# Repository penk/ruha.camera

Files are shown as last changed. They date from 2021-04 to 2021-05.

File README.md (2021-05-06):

# RUHAcam 

A 3D Printable Retro-style Raspberry Pi HQ Camera



## Bill of Materials 

- Raspberry Pi Zero WH + microSD card 
- Raspberry Pi HQ Camera 
- 16mm 10MP Telephoto Lens 
- 2.2" TFT Display 
- TP4056 Micro USB Battery Charger 
- MT3608 DC-DC Step Up Boost Module 
- 2000mAh Lipo battery 
- Power switch 
- Shutter button 
- Dupont jumper wires 
- 3D printed case (see [STL](STL) folder)
- Leather patches for couch (optional)



## Schematic

- Power from converter connects to Pi's `5V` (pin 4) and `GND` (pin 6)
- Shutter button connects to `GPIO26` (pin 37) and `GND` (pin 39) 

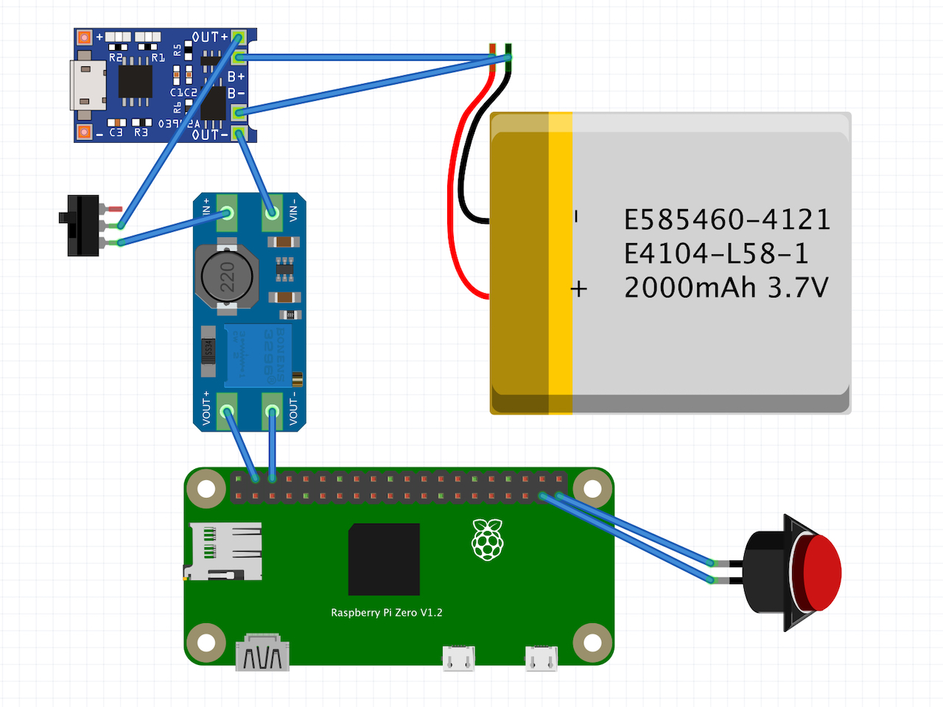
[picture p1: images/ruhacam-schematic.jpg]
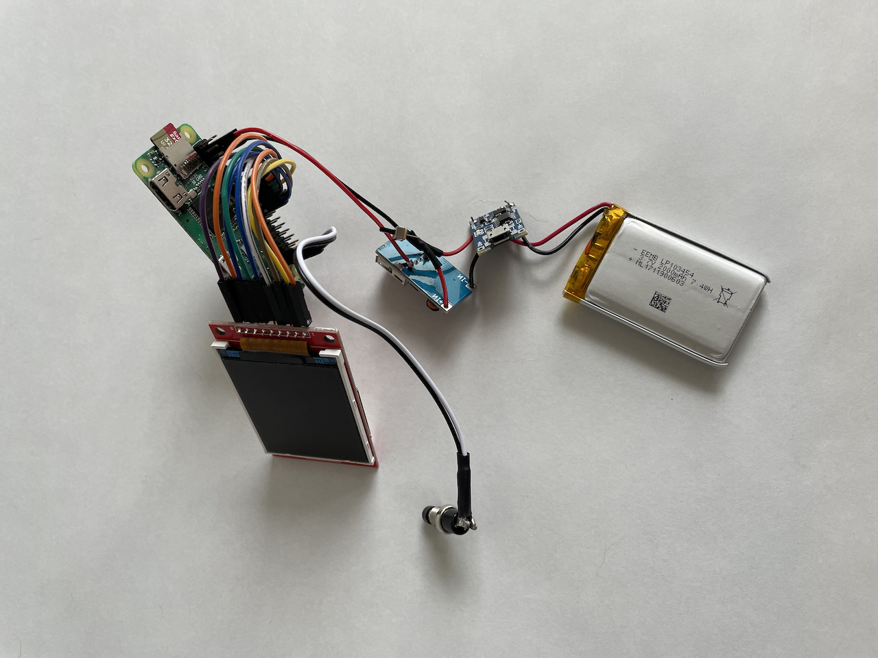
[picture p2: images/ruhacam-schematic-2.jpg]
|  |  |
|-----|-----|

| Raspberry Pi pins | TFT display |
|---|---|
| 3v3 (pin 17) | VCC |
| GND (pin 20) | GND |
| GPIO8 (pin 24) | CS |
| GPIO23 (pin 16) | RESET |
| GPIO24 (pin 18) | DC |
| GPIO10 (pin 19) | MOSI |
| GPIO11 (pin 23) | SCK | 
| GPIO18 (pin 12) | LED | 
| GPIO9 (pin 21) | MISO | 

## Assembly

|  |  |
|---|---|
|  |  |

## Software 

Flash Raspberry Pi OS to micro SD card. Then add following lines into `config.txt`: 

    gpu_mem=256
    dtoverlay=rpi-display
    display_rotate=2

For application, simply execute this script after boot: 

    from gpiozero import Button
    from picamera import PiCamera
    import time

    button = Button(26)

    with PiCamera() as camera:
        camera.resolution = (4056, 3040)
        camera.framerate = 5
        frame = int(time.time())
        camera.start_preview()
        while True:
            button.wait_for_press()
            camera.capture('/home/pi/Pictures/%03d.jpg' % frame)
            frame += 1

## Sample Pictures 

|  |  |
|---|---|
|  |  |

## Copyright and License

Copyright (c) 2021 Ruha Cheng & Penk Chen. All rights reserved. 

All files are licensed under MIT license, see the LICENSE for more information.

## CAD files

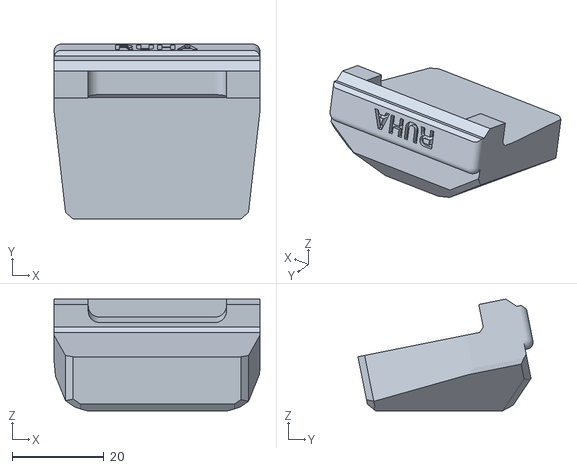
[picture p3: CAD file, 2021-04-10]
STL/ruhacam-top-deco.stl
44.8 x 38.1 x 24.3

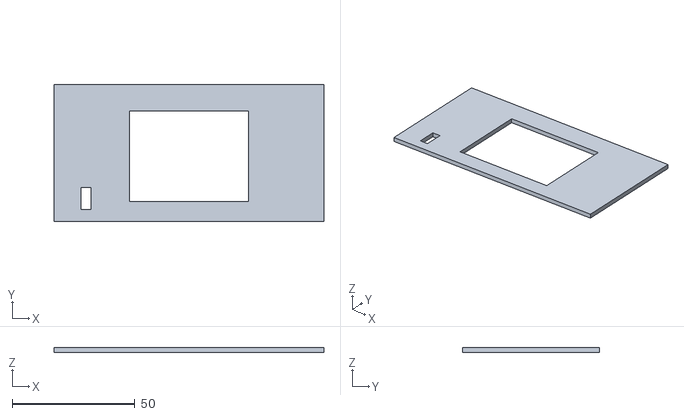
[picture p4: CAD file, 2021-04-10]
STL/ruhacam-cover.stl
109.9 x 55.6 x 2.00

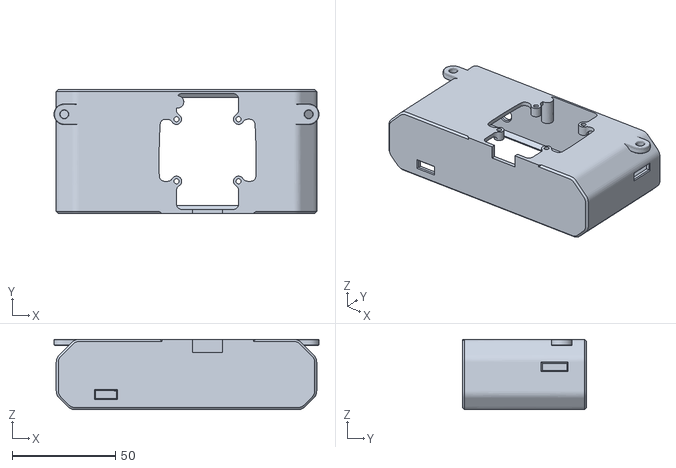
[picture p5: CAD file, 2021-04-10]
STL/ruhacam-body.stl
128.2 x 60.0 x 34.0

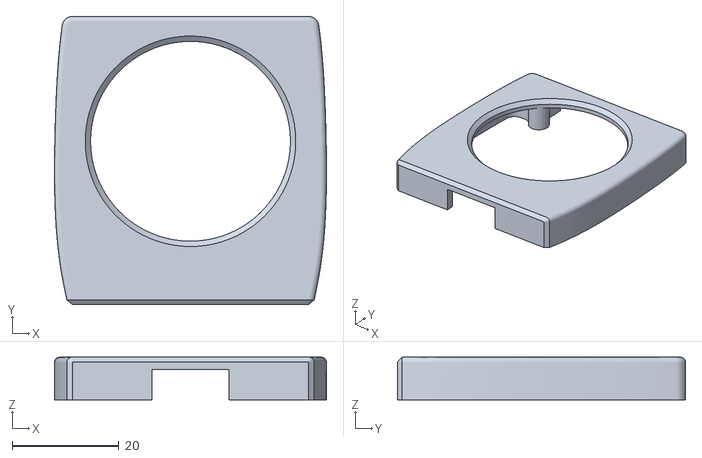
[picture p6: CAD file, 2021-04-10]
STL/ruhacam-mount.stl
50.9 x 54.0 x 8.00

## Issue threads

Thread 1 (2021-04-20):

Did you mean Pi Zero WH?

ghostis, 2021-04-20:
I think the BOM should specify the Pi Zero WH (wireless + header) or specify that you have to solder on the header if you have a Pi Zero W.

penk, 2021-04-21:
Good catch, fixed in latest commit.

Closed 2021-04-21.

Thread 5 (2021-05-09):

Power switch and shutter button

mikecheng2626, 2021-05-09:
Hi,

What kind of power switch and shutter button are they? Just trying to make sure my grocery list is the same.

penk, 2021-05-09:
Hi, I use the spare parts I had at hand, but I believe anything works -- as long as you can tweak the shape on printed parts so it fits.

Amazon link attached for reference:
https://www.amazon.co.jp/dp/B01LYVYQNO
https://www.amazon.co.jp/dp/B0822GHZ36

Closed 2021-05-09.

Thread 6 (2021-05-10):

Link to display?

btilford, 2021-05-10:
Most displays I've found are 2.8"

Also, are some of these parts like the top glued together? The mount looks like it has structure for screws that line up with the main body but, there aren't guide holes.

penk, 2021-05-10:
Hi,

Here's one of those 2.2 TFT I found on Amazon, no affiliation: http://amazon.com/dp/B01CZL6QIQ
All 3D parts are glued; HQ camera and Pi Zero can be screwed into place (or using hot glue if needed).

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

Closed 2021-05-10.

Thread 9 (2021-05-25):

TFT Display Driver

nishabe, 2021-05-25:
I have this display: http://amazon.com/dp/B01CZL6QIQ
However, I have difficulties in making it work.

Could you please share which driver you have used?
Any link to the steps much appreciated.
@penk

RadiantFeline, 2021-05-29:
I'm using the same board with this https://github.com/juj/fbcp-ili9341

penk, 2021-05-30:
Hi, I'm simply using the rpi-display dtoverlay, (`dtoverlay=rpi-display` in `config.txt`).
Source:
https://github.com/raspberrypi/linux/blob/rpi-5.10.y/arch/arm/boot/dts/overlays/rpi-display-overlay.dts

I find this post very helpful:
https://tejaswid.github.io/wikitm/rpi/pi-tft-display

Closed 2021-05-30.

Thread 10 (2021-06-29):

Touch Screen Funtionality?

Nathan116, 2021-06-29:
I was wondering if the 2.2" tft was supposed to be a touchscreen. If not, would it be possible to add touchscreen capabilities to be able to change camera settings on the go? I understand that this is a DIY camera, more of a "proof-of-concept" than anything else, but I just feel like having the ability to change some of the basic camera settings in the camera would be cool.

penk, 2021-07-01:
Hi @Nathan116, you're right, touch support is part of the plan.

We might have to opt for 2.4" tft with touch (e.g. https://www.amazon.com/2-4-tft-spi-touch/s?k=2.4+tft+spi+touch)
And we are also working with the developer of [this project](https://github.com/monstercameron/pi-camera-gui ) for the UI. If you are interested in commit bits, please let me know!

Nathan116, 2021-07-01:
@penk that is exactly what I was looking for! I'm not sure what you mean by commit bits, but I'd be interested in helping to develop the program, though, I'm not too sure how.much if a help I'd be given that I don't have a whole lot of coding experience and have never coded anything in python.

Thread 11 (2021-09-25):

display problems

Johnephen, 2021-09-25:
I took a 2.2 "TFT display as recommended and connected it, but a problem emerged.
Display Link (https://www.amazon.de/gp/product/B01E0MGZU2/ref=ppx_yo_dt_b_asin_title_o07_s00?ie=UTF8&psc=1)

In a blog it was shown how it can be connected to the Raspberry Pi and in the linked Github project this was also discussed again. But I have a problem that wasn't described there. After starting the script, the image can only be seen in the upper right part of the display, greatly reduced. Unfortunately, the autostart script does not work properly either. I have to run the script to add it to the autostart after every reboot. In addition, the displayed image flickers as if the frame rate is incorrect.
The Blog(in German)(https://blog.gc2.at/post/spi-tft-lcd-kernel5/)
the GitHubProjekt(english)(https://github.com/juj/fbcp-ili9341)

I very much hope that a solution can be found and that everything works out. Many thanks in advance.

penk, 2021-09-26:
Hi @Johnephen, thank you for the issue report.

It seems like in your current implementation, you're using a different kernel driver (mentioned in the blog) and fbcp command to mirror main output to your display. There are many variables here (and many options) so let me try to provide my way of thinking for your reference:

- For the resolution (image only in upper right part) issue, I would check if `gpu_mem=256` is added in `/boot/config.txt`. It's essential for the camera to take the full resolution.
- For the not-auto-start script issue, I'd recommend adding a `.desktop` file under `/etx/xdg/autostart` folder. You can find more information in this link: https://help.gnome.org/admin/system-admin-guide/stable/autostart-applications.html.en
(And of course you'll need to change the `Exec=` line to the path of your script)
- The flicking and frame rate issue seems to be related to the fbcp command itself, I'd check if correct build flags are used in compiling fbcp

And finally, if it still fails you, please try using the original Raspberry Pi OS overlay driver like I did and see if it works better for you. We had a ticket on that here:
https://github.com/penk/ruha.camera/issues/11

Good luck!

Johnephen, 2021-09-26:
Thank you for this so quick response. I kept looking around for display solutions and a video that actually solved all of my display issues. The autostart also works and the camera script also works. So when I start the Raspberry Pi, I also have a playback of the camera. But I'm still a little dissatisfied with the refresh rate of the playback itself, since that of the display should actually be ok. But I'll look at that again later, whether it's really on the display or on the playback. But thanks again for the answer.

Video I used: https://www.youtube.com/watch?v=uz4sa24C4gk&list=LL&index=4&t=1015s

penk, 2021-09-26:
@Johnephen thanks for the link, I'll look into it too. Feel free to close this issue, if you like.

Closed 2021-09-26.

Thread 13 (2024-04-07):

Update code for Bookworm

earboxer, 2024-04-07:
Trying to use picamera on bookworm fails:

```
>>> from picamera import PiCamera
Traceback (most recent call last):
  File "<stdin>", line 1, in <module>
  File "/usr/lib/python3/dist-packages/picamera/__init__.py", line 72, in <module>
    from picamera.exc import (
  File "/usr/lib/python3/dist-packages/picamera/exc.py", line 41, in <module>
    import picamera.mmal as mmal
  File "/usr/lib/python3/dist-packages/picamera/mmal.py", line 49, in <module>
    _lib = ct.CDLL('libmmal.so')
           ^^^^^^^^^^^^^^^^^^^^^
  File "/usr/lib/python3.11/ctypes/__init__.py", line 376, in __init__
    self._handle = _dlopen(self._name, mode)
                   ^^^^^^^^^^^^^^^^^^^^^^^^^
OSError: libmmal.so: cannot open shared object file: No such file or directory
```

now that I have a raspberry pi camera, I'm getting this error, so I'm not completely sure how to set it up in bookworm.

```
[0:23:50.367964185] [2423]  INFO Camera camera_manager.cpp:284 libcamera v0.2.0+46-075b54d5
Preview window unavailable
ERROR: *** no cameras available ***
```

(Presumably if I use some older version of raspberry pi OS, it will work?)

earboxer, 2024-04-20:
[after a good amount of tinkering,] I have a workable proof of concept running in bookworm:

## Edit `config.txt`
Edit your `config.txt` file, adding the dtoverlay for your screen
    * For [my screen](https://www.amazon.com/PiTFT-Display-240x240-Raspberry-ST7789/dp/B08F9XTKGK), I added `dtoverlay=fbtft,st7789v,dc=25,cs=8,dc_pin=25,cs_pin=8,dc-gpios=25,height=240,width=240,cs-gpios=8`
    * (you should also have `camera_auto_detect=1`)
    * on reboot, you should have a /dev/fb1 device that appears eventually. You test this using `con2fbmap 1 1`, which will show your shell on that screen, but that's optional.

## Python script
Have this python script (you need picamera2, and python3-opencv)

```py
#!/usr/bin/env python3

# For YUV420/YUYV to RGB, do
# sudo apt install python3-opencv
from picamera2 import Picamera2, Preview
from gpiozero import Button
import time
picam2 = Picamera2()
shutter = Button(24)
quitter = Button(23)

# probably could be optimized better...
camera_config = picam2.create_still_configuration(main={"size": (1920, 1080)}, lores={"size": (240, 240)}, display="lores")
# "fps":10.0 # TODO: howto set fps???
picam2.configure(camera_config)
#picam2.start_preview(Preview.QTGL)
#picam2.start_preview(Preview.DRM) # Failed to find...
picam2.start_preview(Preview.QT)
picam2.start()

num=0
while True:
    shutter.wait_for_press()
    now = time.localtime()
    picam2.capture_file(
        f"{now.tm_year}{now.tm_mon:02}{now.tm_mday:02}_{now.tm_hour:02}{now.tm_min:02}{now.tm_sec:02}_{num}.jpg"
    )
    num = num + 1
```

(there's some backstory about raspberry pi zero not having DRM support/GPU acceleration)

## Launching it with correct env values

`QT_QPA_PLATFORM=linuxfb:fb=/dev/fb1 ./picamera.py`

(this tells QT that you want it to render to the linuxfb at /dev/fb1)

## Caveats
* It takes a little over a minute to launch the script
* the framebuffer mouse appears in the top left corner
* After you take a picture, it freezes for a few hundred milliseconds
* the screen dims itself after a bit

But the latency and framerate are not *horrible*...

## Sources/useful references
* [picamera2 reference (November 2023)](https://datasheets.raspberrypi.com/camera/picamera2-manual.pdf)
* [Some QT forum topic, which got me the way to output to fb1 (January 2021)](https://forum.qt.io/topic/122950/qt-5-5-1-can-t-display-in-linuxfb-fb1)
* [Why you can't use DRM/wayland on pi-zero (March 2018)](https://www.joshondesign.com/2018/03/26/linux_graphics_state)
    * [Wayland only works on pi-4 or pi-5, "earlier platforms [are] still being optimised" (October 2023)](https://www.raspberrypi.com/news/bookworm-the-new-version-of-raspberry-pi-os/)
* [How to connect your camera to your pi](https://docs.arducam.com/Raspberry-Pi-Camera/Native-camera/Quick-Start-Guide/)

If you're having trouble setting up your fbtft overlay, use e.g. `journalctl -t kernel --system -S 2024-04-19\ 21:00` on raspberry pi os to see kernel messages, which might include useful fbtft information.

Don't use raspberry pi OS 'lite' image. It will probably not connect to WiFi. (probably you want to start with the ["Raspberry Pi OS with desktop"](https://www.raspberrypi.com/software/operating-systems/#raspberry-pi-os-32-bit), then uninstall/disable the desktop environment.)

maybe [this stackoverflow is useful information?](https://raspberrypi.stackexchange.com/questions/78334/what-have-you-done-to-make-generic-tft-touchscreen-display-work)
